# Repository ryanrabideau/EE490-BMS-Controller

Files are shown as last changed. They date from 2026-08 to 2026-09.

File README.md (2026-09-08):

# EE 490 - 24V Li-ion Battery Management System

This repository contains the hardware and firmware development for our EE 490 senior design project: a Battery Management System (BMS) for a custom **2P7S lithium-ion battery pack**.

The system uses an **STM32F411RE** microcontroller with an **ST L9963E** battery monitoring AFE and L9963T interface. The goal is to monitor individual cell voltages, pack current, temperature, and state of charge while providing fault detection, UART telemetry, and active cell balancing.

## System Overview

- **Battery configuration:** 2P7S
- **Cells:** Samsung INR18650-25R, 2.5 Ah per cell
- **Pack capacity:** 5.0 Ah
- **Nominal pack voltage:** 25.2 V
- **MCU:** STM32F411RE
- **Battery monitoring AFE:** ST L9963E
- **AFE interface:** ST L9963T
- **MCU/AFE communication:** SPI2
- **Telemetry:** USART2 UART
- **Firmware:** C using STM32 HAL
- **Balancing:** Chained switched-capacitor active balancing

## Firmware

The STM32 firmware is located in [`firmware/EE490BMS/`](firmware/EE490BMS/).

Communication with the L9963E is handled through the L9963T interface. The low-level driver handles register communication with the AFE, while the application layer processes the measurements and keeps track of the overall BMS state.

The firmware currently supports:

- L9963E initialization and addressing
- Register reads and writes
- Cell-voltage acquisition
- Pack-voltage calculation
- Minimum and maximum cell-voltage tracking
- Cell-to-cell voltage delta calculation
- Cell undervoltage and overvoltage detection
- Pack-current measurement using the L9963E current ADC
- Coulomb counting
- State-of-charge estimation
- Raw GPIO acquisition for the thermistors
- UART telemetry
- Communication and measurement timeouts
- Validity tracking for voltage, current, Coulomb-counting, and SoC data

The main application currently runs as a simple superloop with approximately one update per second. FreeRTOS files are still present in the generated STM32 project, but the BMS application itself does not currently use the RTOS scheduler.

## Current Progress

Communication between the STM32F411RE and L9963E is working, including device addressing and register reads/writes. Cell-voltage measurements have also been read successfully from the current four-cell bench setup.

The higher-level firmware for the final 7S system is now in place. This includes voltage processing, voltage fault detection, current sensing, Coulomb counting, SoC estimation, and UART telemetry. The current and Coulomb-counting code still needs to be validated on the complete hardware setup.

The final pack will use seven series cell groups, but the current bench configuration only enables **CELL1, CELL2, CELL13, and CELL14** on the L9963E. The final seven-cell channel mapping will be confirmed when the complete pack is connected.

Current sensing is implemented using the L9963E's 18-bit current ADC. The firmware currently contains a temporary **0.1 mΩ shunt value**, which will be replaced once the final shunt resistance is confirmed. Current polarity also needs to be verified on the physical hardware before the SoC calculation is considered final.

Temperature acquisition is partially implemented. The firmware can read the seven GPIO channels intended for the thermistors and convert the raw ADC values to voltages, but the final voltage-to-temperature conversion has not been added yet.

Active balancing is also still under development. The planned system uses a chained switched-capacitor topology, with the balancing hardware controlled by the STM32.

## UART Telemetry

The latest BMS measurements can be formatted and transmitted over USART2 for debugging and monitoring from a PC.

Example output:

```text
PACK: 25.184 V | CELLS: 3.598 3.602 3.596 3.600 3.595 3.601 3.592 V | CURRENT: -1.243 A | SOC: 81.7 % | VALID[V:1 I:1 SOC:1]
```

The validity flags make it possible to distinguish valid measurements from failed or incomplete AFE communication.

## Repository Structure

- [`firmware/`](firmware/) - STM32 firmware
  - [`EE490BMS/`](firmware/EE490BMS/) - Main STM32CubeIDE project
  - [`Core/Inc/`](firmware/EE490BMS/Core/Inc/) - Application and driver headers
  - [`Core/Src/`](firmware/EE490BMS/Core/Src/) - Application, driver, and STM32 source files
  - [`EE490BMS.ioc`](firmware/EE490BMS/EE490BMS.ioc) - STM32CubeMX configuration
- [`hardware/`](hardware/) - Battery pack, enclosure, and mechanical CAD
  - [`STL Exports/`](hardware/STL%20Exports/) - Exported 3D-printable parts
  - [`Vendor/`](hardware/Vendor/) - Vendor component models
- [`docs/`](docs/) - Project documentation
- [`pc_interface/`](pc_interface/) - PC-side interface development

## Main Firmware Files

[`bms_app.c`](firmware/EE490BMS/Core/Src/bms_app.c) and [`bms_app.h`](firmware/EE490BMS/Core/Inc/bms_app.h) contain the higher-level BMS logic, including voltage processing, current measurement, Coulomb counting, SoC estimation, fault detection, and telemetry.

[`L9963E_utils.c`](firmware/EE490BMS/Core/Src/L9963E_utils.c) and [`L9963E_utils.h`](firmware/EE490BMS/Core/Inc/L9963E_utils.h) provide the interface between the application layer and the L9963E driver.

[`L9963E.c`](firmware/EE490BMS/Core/Src/L9963E.c) and [`L9963E_drv.c`](firmware/EE490BMS/Core/Src/L9963E_drv.c) contain the lower-level L9963E functionality and communication.

[`stm32_if.c`](firmware/EE490BMS/Core/Src/stm32_if.c) provides the STM32 hardware interface used by the L9963E driver.

[`main.c`](firmware/EE490BMS/Core/Src/main.c) contains the STM32 initialization and main BMS superloop.

## Building the Firmware

The firmware is developed using **STM32CubeIDE** and **STM32CubeMX**.

The CubeIDE project is located in:

[`firmware/EE490BMS/`](firmware/EE490BMS/)

Import the project into STM32CubeIDE and build the Debug configuration. The current shared firmware builds with **0 errors and 0 warnings**.

## Remaining Work

The main remaining work is hardware integration and validation. This includes confirming the final seven-cell L9963E mapping, verifying the current shunt value and polarity, testing Coulomb-counting accuracy, validating SoC behavior during charge and discharge, completing the thermistor temperature conversion, and implementing the active-balancing control.

Mechanical work on the battery pack and control enclosure is also still in progress. Current SolidWorks assemblies and exported STL files can be found in the [`hardware/`](hardware/) directory.

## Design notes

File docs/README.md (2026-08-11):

System block diagrams, schematics, and register maps.

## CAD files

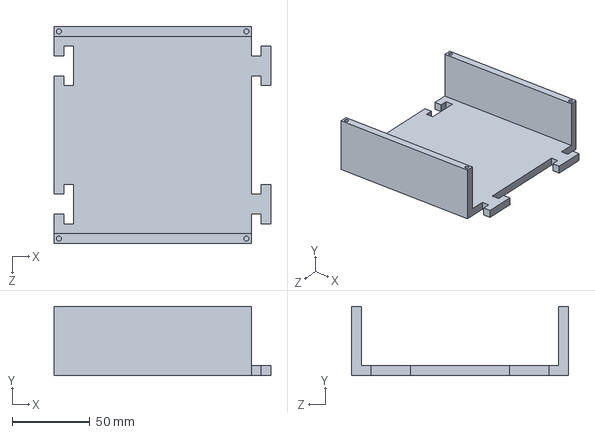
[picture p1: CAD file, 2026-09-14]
hardware/Battery Mount Middle.SLDPRT
139.7 x 44.5 x 139.7 mm

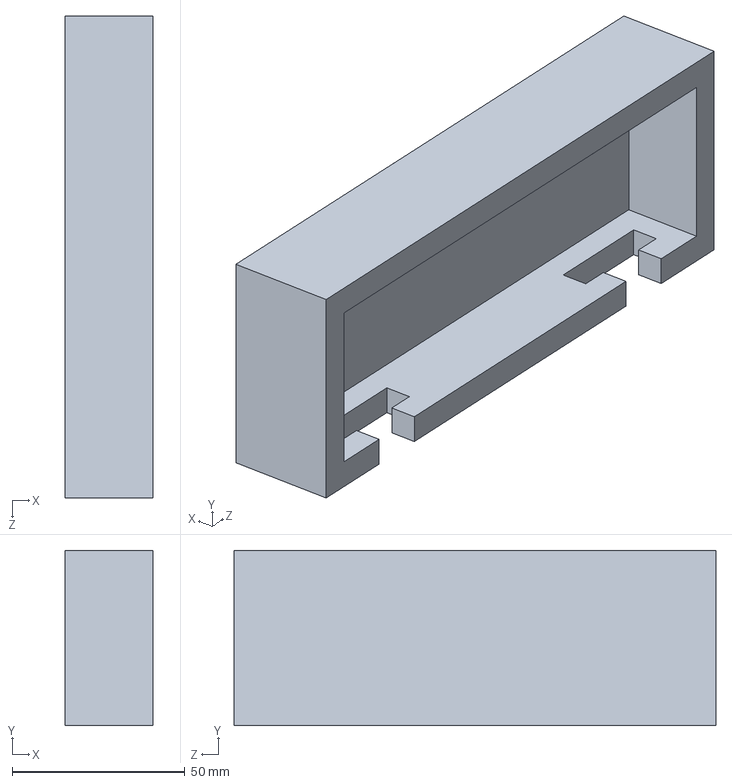
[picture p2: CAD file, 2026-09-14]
hardware/End Cap.SLDPRT
25.4 x 50.8 x 139.7 mm

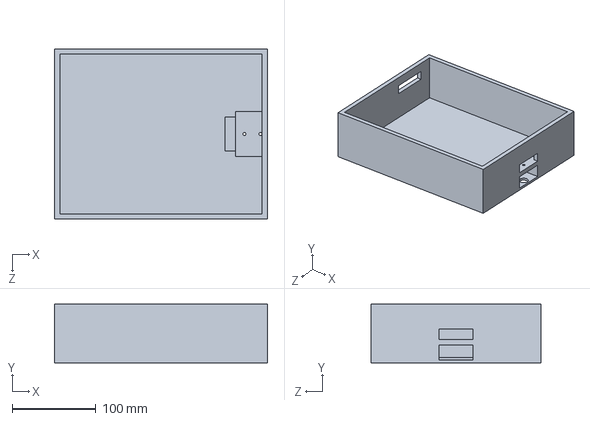
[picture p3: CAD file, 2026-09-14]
hardware/Control Enclosure.SLDPRT
254.0 x 69.8 x 203.2 mm

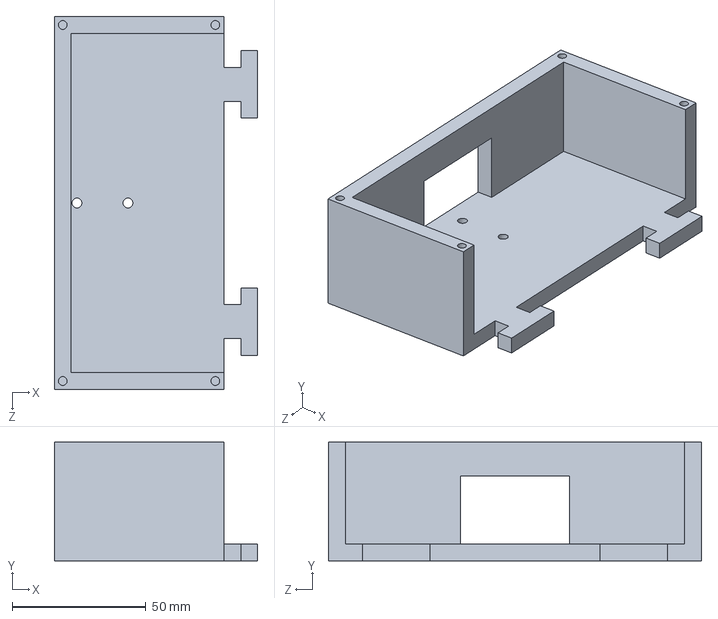
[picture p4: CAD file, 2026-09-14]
hardware/Battery Connector.SLDPRT
76.2 x 44.5 x 139.7 mm

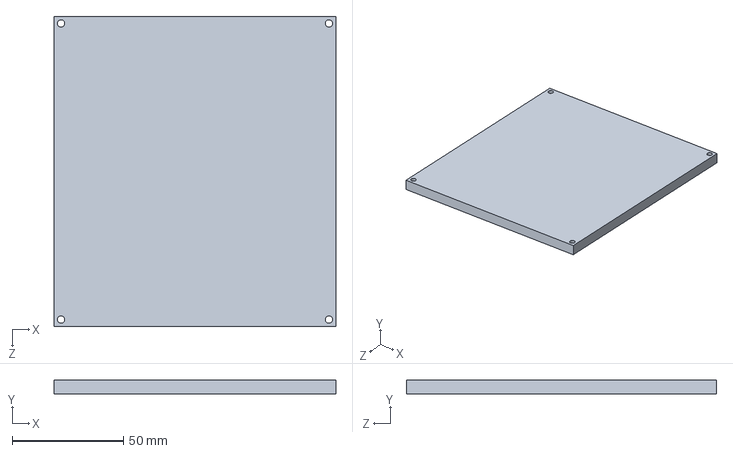
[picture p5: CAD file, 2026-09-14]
hardware/Battery Mount Middle Lid.SLDPRT
127.0 x 6.35 x 139.7 mm

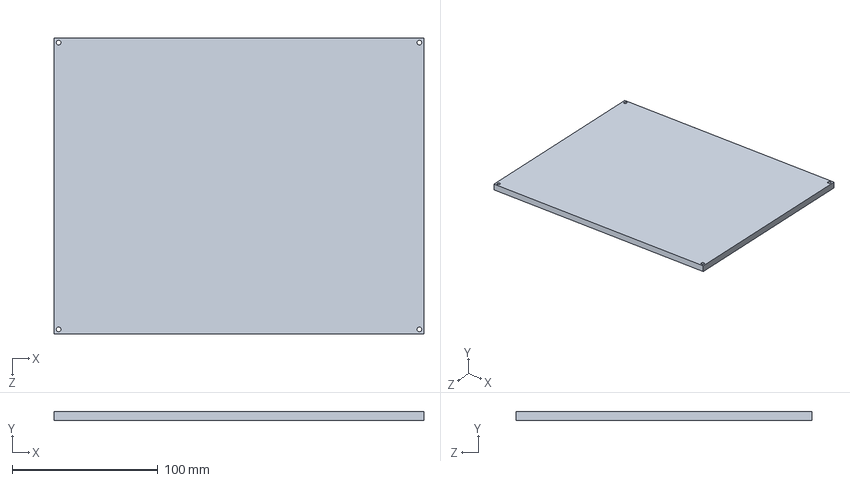
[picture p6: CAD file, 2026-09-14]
hardware/Control Enclosure Lid.SLDPRT
254.0 x 6.35 x 203.2 mm

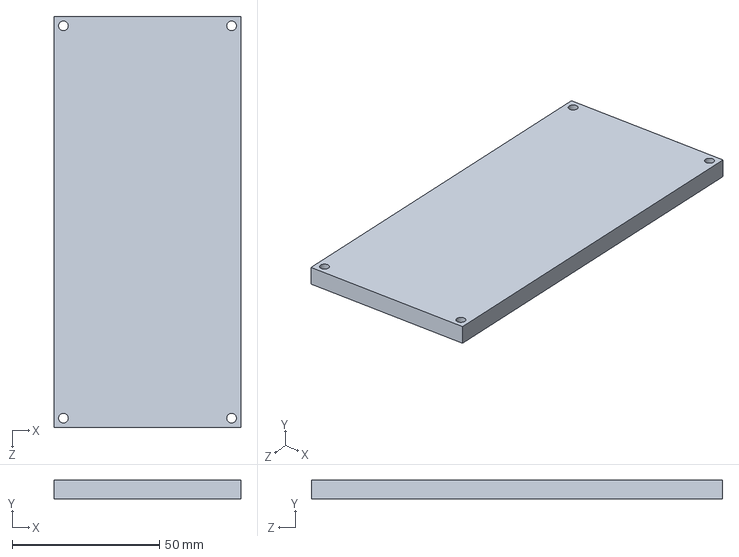
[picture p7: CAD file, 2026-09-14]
hardware/Battery Connector Lid.SLDPRT
63.5 x 6.35 x 139.7 mm

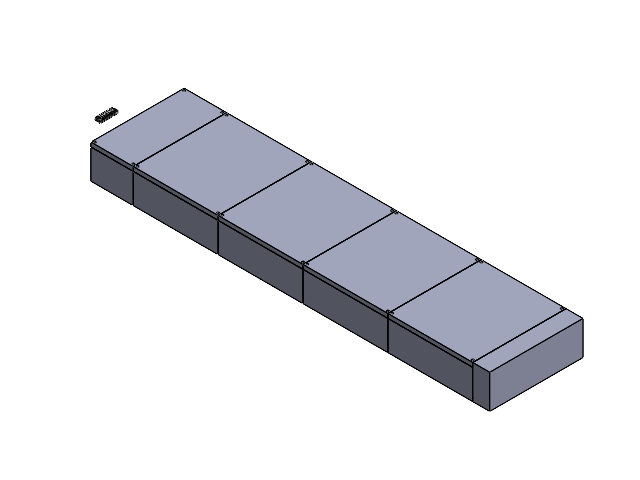
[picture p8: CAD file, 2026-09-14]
hardware/Battery Sub Component.SLDASM
BATTERY HOLDER x 8
Battery Mount Middle x 4
Battery Mount Middle Lid x 4
End Cap
Battery Connector
Anderson SB50
modele_pin.step x 10
Housing.step
Battery Connector Lid

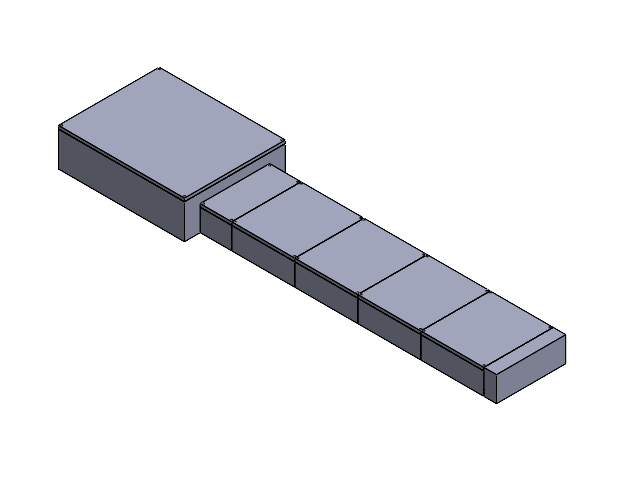
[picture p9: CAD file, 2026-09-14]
hardware/Layout.SLDASM
BATTERY HOLDER x 8
Battery Mount Middle x 4
Battery Mount Middle Lid x 4
End Cap
Battery Connector
Anderson SB50 x 2
modele_pin.step x 10
Housing.step
Battery Connector Lid
Control Enclosure
AEK-POW-BMSWTX Circuitboard
Pin.step x 10
Top_entry_base.step
MB1136 rev C.STEP
cn6.STEP
cn4.STEP
cn9.STEP
cn10.STEP
b1.STEP
b2.STEP
STM32lqfp64.STEP
cn8.STEP
cn7.STEP
jp1 kon.STEP x 2
cn1.STEP
X1_NUCLEO-F401RE.STEP
additional_NUCLEO-F401RE.STEP
jp1.STEP x 2
Jumper 1.STEP x 6
jp2_3 pin .STEP
jp2_2 pin.STEP x 2
T2.STEP
X2.STEP
L3.STEP
STM32F446RET6U.STEP
Breadboard
Control Enclosure Lid

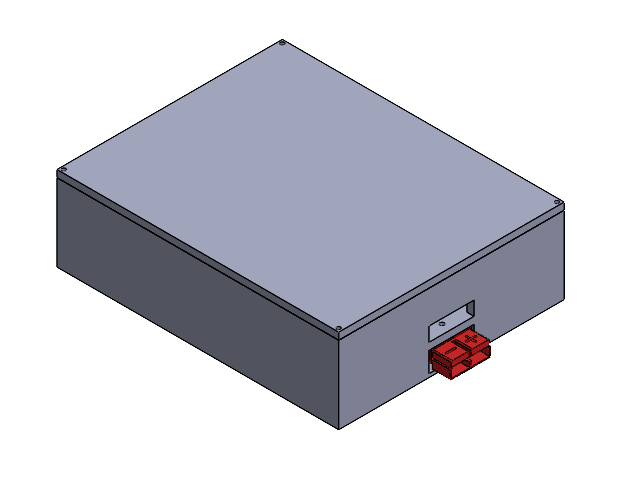
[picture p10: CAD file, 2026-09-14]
hardware/Control Assembly.SLDASM
Control Enclosure
AEK-POW-BMSWTX Circuitboard
Anderson SB50
Pin.step x 10
Top_entry_base.step
MB1136 rev C.STEP
cn6.STEP
cn4.STEP
cn9.STEP
cn10.STEP
b1.STEP
b2.STEP
STM32lqfp64.STEP
cn8.STEP
cn7.STEP
jp1 kon.STEP x 2
cn1.STEP
X1_NUCLEO-F401RE.STEP
additional_NUCLEO-F401RE.STEP
jp1.STEP x 2
Jumper 1.STEP x 6
jp2_3 pin .STEP
jp2_2 pin.STEP x 2
T2.STEP
X2.STEP
L3.STEP
STM32F446RET6U.STEP
Breadboard
Control Enclosure Lid

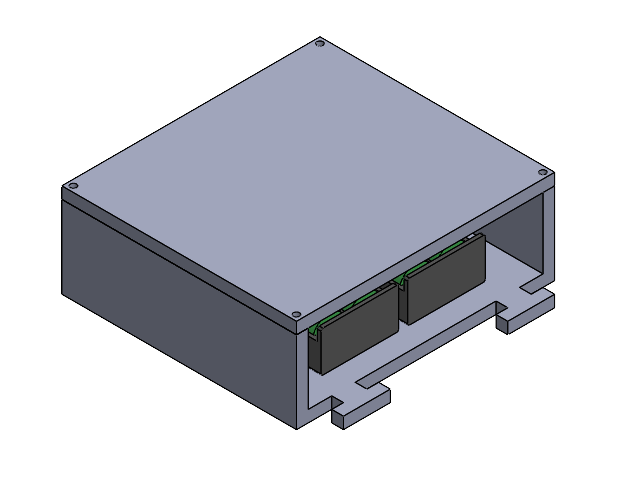
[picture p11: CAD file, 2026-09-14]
hardware/Middle Battery Setup.SLDASM
BATTERY HOLDER x 2
Battery Mount Middle
Battery Mount Middle Lid

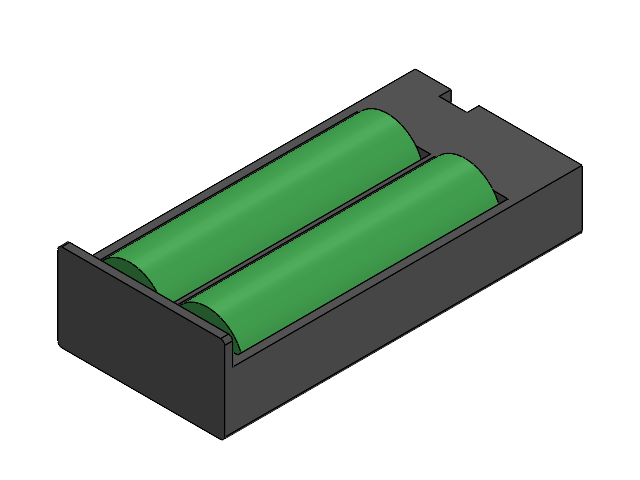
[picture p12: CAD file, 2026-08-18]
hardware/Filled Battery Holder.SLDASM
BATTERY HOLDER

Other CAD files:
hardware/STL Exports/Battery Connector Lid.STL
hardware/STL Exports/Battery Connector.STL
hardware/STL Exports/Battery Mount Middle Lid.STL
hardware/STL Exports/Battery Mount Middle.STL
hardware/STL Exports/Control Enclosure Lid.STL
hardware/STL Exports/Control Enclosure.STL
hardware/STL Exports/End Cap.STL

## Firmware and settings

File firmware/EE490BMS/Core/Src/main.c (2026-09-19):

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
/* Includes ------------------------------------------------------------------*/
#include "main.h"
#include "cmsis_os.h"

/* USER CODE BEGIN Includes */
#include "L9963E_utils.h"
#include "bms_app.h"
#include <stdint.h>
#include "THERMISTOR.h"
/* USER CODE END Includes */

ADC_HandleTypeDef hadc1;
DMA_HandleTypeDef hdma_adc1;

SPI_HandleTypeDef hspi2;

TIM_HandleTypeDef htim1;

UART_HandleTypeDef huart2;

/* Definitions for defaultTask */
osThreadId_t defaultTaskHandle;
const osThreadAttr_t defaultTask_attributes = {
  .name = "defaultTask",
  .stack_size = 128 * 4,
  .priority = (osPriority_t) osPriorityNormal,
};
void SystemClock_Config(void);
static void MX_GPIO_Init(void);
static void MX_DMA_Init(void);
static void MX_USART2_UART_Init(void);
static void MX_TIM1_Init(void);
static void MX_SPI2_Init(void);
static void MX_ADC1_Init(void);
void StartDefaultTask(void *argument);

/**
  * @brief  The application entry point.
  * @retval int
  */
int main(void)
{

  /* MCU Configuration--------------------------------------------------------*/

  /* Reset of all peripherals, Initializes the Flash interface and the Systick. */
  HAL_Init();

  /* Configure the system clock */
  SystemClock_Config();

  /* Initialize all configured peripherals */
  MX_GPIO_Init();
  MX_DMA_Init();
  MX_USART2_UART_Init();
  MX_TIM1_Init();
  MX_SPI2_Init();
  MX_ADC1_Init();
  /* USER CODE BEGIN 2 */

  char telemetryBuffer[256];
  int telemetryLength;
  uint32_t adcBuffer[4] = {0};	//0 is shunt current, 1-3 is temp
  float current = 0;
  float temp1 = 0;
  float temp2 = 0;
  float temp3 = 0;


  // Flash LED on board for reference and startup
  HAL_GPIO_WritePin(LD2_GPIO_Port, LD2_Pin, GPIO_PIN_SET);
  HAL_Delay(100);
  HAL_GPIO_WritePin(LD2_GPIO_Port,  LD2_Pin, GPIO_PIN_RESET);

  //Initialize global variable states
  BMS_App_Init();

  //Initialize and address the L9963E AFE.
  L9963E_utils_init();

  //Known SOC starting value
  BMS_App_SetSocReference(80.0f);

  HAL_GPIO_WritePin(SW_EVEN_GPIO_Port, SW_EVEN_Pin, GPIO_PIN_RESET);
  HAL_GPIO_WritePin(SW_ODD_GPIO_Port, SW_ODD_Pin, GPIO_PIN_RESET);


  //Used to test switching circuit

//  while (1) {
//	  HAL_GPIO_WritePin(SW_EVEN_GPIO_Port, SW_EVEN_Pin, GPIO_PIN_SET);
//	  HAL_Delay(10);
//	  HAL_GPIO_WritePin(SW_EVEN_GPIO_Port, SW_EVEN_Pin, GPIO_PIN_RESET);
//	  HAL_Delay(10);
//
//	  HAL_GPIO_WritePin(SW_ODD_GPIO_Port, SW_ODD_Pin, GPIO_PIN_SET);
//	  HAL_Delay(10);
//	  HAL_GPIO_WritePin(SW_ODD_GPIO_Port, SW_ODD_Pin, GPIO_PIN_RESET);
//	  HAL_Delay(10);
//  }

  HAL_NVIC_DisableIRQ(DMA2_Stream0_IRQn);
  HAL_ADC_Start_DMA(&hadc1, adcBuffer, 4);	//Start ADC with DMA of size 4

  // Super loop
  while (1)
  {
	  current = (adcBuffer[0]/(4096e0f))*6000;	// To mA
	  temp1 = Thermistor_ReadF(adcBuffer[1], 1);
	  temp2 = Thermistor_ReadF(adcBuffer[2], 0);
	  temp3 = Thermistor_ReadF(adcBuffer[3], 0);

	  BMS_App_SetExternalMeasurements(current, temp1, temp2, temp3);

	  BMS_App_UpdateAll();

	  const BMS_FaultData_t *faultData = BMS_App_GetFaultData();

	  if ((faultData != NULL) && !faultData->faultActive &&
			  temp1 < 85 && temp2 < 85 && temp3 < 85 && current < 2000)
	  {
	      HAL_GPIO_WritePin(MASTER_SWITCH_GPIO_Port, MASTER_SWITCH_Pin, GPIO_PIN_SET);
	  }
	  else
	  {
	      HAL_GPIO_WritePin(MASTER_SWITCH_GPIO_Port, MASTER_SWITCH_Pin, GPIO_PIN_RESET);
	  }

	  telemetryLength = BMS_App_FormatTelemetry(telemetryBuffer, sizeof(telemetryBuffer));

      if (telemetryLength > 0)
      {
          /*
           * snprintf() returns the number of characters
           * that would have been written.
           *
           * Limit transmission to the bytes actually
           * stored in telemetryBuffer.
           */
          uint16_t transmitLength = (telemetryLength < (int)sizeof(telemetryBuffer)) ?
              (uint16_t)telemetryLength :
              (uint16_t) (sizeof(telemetryBuffer) - 1U);

          HAL_UART_Transmit(&huart2, (uint8_t *)telemetryBuffer, transmitLength, HAL_MAX_DELAY);
      }

      //Keep Coulomb-counter servicing within the intended approximately one-second interval.
	  HAL_GPIO_WritePin(SW_EVEN_GPIO_Port, SW_EVEN_Pin, GPIO_PIN_SET);
	  HAL_Delay(10);
	  HAL_GPIO_WritePin(SW_EVEN_GPIO_Port, SW_EVEN_Pin, GPIO_PIN_RESET);
	  HAL_Delay(10);

	  HAL_GPIO_WritePin(SW_ODD_GPIO_Port, SW_ODD_Pin, GPIO_PIN_SET);
	  HAL_Delay(10);
	  HAL_GPIO_WritePin(SW_ODD_GPIO_Port, SW_ODD_Pin, GPIO_PIN_RESET);
	  HAL_Delay(10);
  }

  /* USER CODE END 2 */

  /* Init scheduler */
  osKernelInitialize();

  /* USER CODE BEGIN RTOS_MUTEX */
  /* add mutexes, ... */
  /* USER CODE END RTOS_MUTEX */

  /* USER CODE BEGIN RTOS_SEMAPHORES */
  /* add semaphores, ... */
  /* USER CODE END RTOS_SEMAPHORES */

  /* USER CODE BEGIN RTOS_TIMERS */
  /* start timers, add new ones, ... */
  /* USER CODE END RTOS_TIMERS */

  /* USER CODE BEGIN RTOS_QUEUES */
  /* add queues, ... */
  /* USER CODE END RTOS_QUEUES */

  /* Create the thread(s) */
  /* creation of defaultTask */
  defaultTaskHandle = osThreadNew(StartDefaultTask, NULL, &defaultTask_attributes);

  /* USER CODE BEGIN RTOS_THREADS */
  /* add threads, ... */
  /* USER CODE END RTOS_THREADS */

  /* USER CODE BEGIN RTOS_EVENTS */
  /* add events, ... */
  /* USER CODE END RTOS_EVENTS */

  /* Start scheduler */
  osKernelStart();

  /* We should never get here as control is now taken by the scheduler */

  /* Infinite loop */
  /* USER CODE BEGIN WHILE */
  while (1)
  {
    /* USER CODE END WHILE */

    /* USER CODE BEGIN 3 */
  }
  /* USER CODE END 3 */
}

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
/* USER CODE BEGIN Header_StartDefaultTask */
/**
  * @brief  Function implementing the defaultTask thread.
  * @param  argument: Not used
  * @retval None
  */
/* USER CODE END Header_StartDefaultTask */
void StartDefaultTask(void *argument)
{
  /* USER CODE BEGIN 5 */

  /* Infinite loop */
  for (;;)
  {
    osDelay(1);
  }

  /* USER CODE END 5 */
}

/**
  * @brief  Period elapsed callback in non blocking mode
  * @note   This function is called  when TIM5 interrupt took place, inside
  * HAL_TIM_IRQHandler(). It makes a direct call to HAL_IncTick() to increment
  * a global variable "uwTick" used as application time base.
  * @param  htim : TIM handle
  * @retval None
  */
void HAL_TIM_PeriodElapsedCallback(TIM_HandleTypeDef *htim)
{
  if (htim->Instance == TIM5)
  {
    HAL_IncTick();
  }
}

/**
  * @brief  This function is executed in case of error occurrence.
  * @retval None
  */
void Error_Handler(void)
{
  /* USER CODE BEGIN Error_Handler_Debug */

  /* User can add his own implementation to report the HAL error return state */

  __disable_irq();

  while (1)
  {
  }

  /* USER CODE END Error_Handler_Debug */
}
#ifdef USE_FULL_ASSERT
/**
  * @brief  Reports the name of the source file and the source line number
  *         where the assert_param error has occurred.
  * @param  file: pointer to the source file name
  * @param  line: assert_param error line source number
  * @retval None
  */
void assert_failed(uint8_t *file, uint32_t line)
{
  /* USER CODE BEGIN 6 */

  /* User can add his own implementation to report the file name and line number,
     ex: printf("Wrong parameters value: file %s on line %d\r\n", file, line) */

  /* USER CODE END 6 */
}
#endif /* USE_FULL_ASSERT */

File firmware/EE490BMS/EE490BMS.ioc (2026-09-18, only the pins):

Mcu.UserName=STM32F411RETx
PA0-WKUP.Signal=ADCx_IN0
PA13.GPIO_Label=TMS
PA13.Signal=SYS_JTMS-SWDIO
PA14.GPIO_Label=TCK
PA14.Signal=SYS_JTCK-SWCLK
PA2.GPIO_Label=USART_TX
PA2.Signal=USART2_TX
PA3.GPIO_Label=USART_RX
PA3.Signal=USART2_RX
PA4.Signal=ADCx_IN4
PA5.GPIO_Label=LD2 [Green Led]
PA5.Signal=GPIO_Output
PA6.Signal=ADCx_IN6
PA7.Signal=ADCx_IN7
PB0.GPIO_Label=L9963T_ISOFREQ_GPIO_OUT
PB0.Signal=GPIO_Output
PB1.GPIO_Label=L9963T_BNE_GPIO_IN
PB1.Signal=GPIO_Input
PB10.GPIO_Label=L9963T_SCK_SPI_SCK
PB10.Signal=SPI2_SCK
PB2.GPIO_Label=L9963T_TXEN_GPIO_OUT
PB2.Signal=GPIO_Output
PB3.GPIO_Label=SWO
PB3.Signal=SYS_JTDO-SWO
PB5.GPIO_Label=MASTER_SWITCH
PB5.Signal=GPIO_Output
PC0.GPIO_Label=SW_EVEN
PC0.Signal=GPIO_Output
PC1.GPIO_Label=SW_ODD
PC1.Signal=GPIO_Output
PC13-ANTI_TAMP.GPIO_Label=B1 [Blue PushButton]
PC13-ANTI_TAMP.Signal=GPXTI13
PC14-OSC32_IN.Signal=RCC_OSC32_IN
PC15-OSC32_OUT.Signal=RCC_OSC32_OUT
PC2.GPIO_Label=L9963T_SDO_SPI_MISO
PC2.Signal=SPI2_MISO
PC3.GPIO_Label=L9963T_SDI_SPI_MOSI
PC3.Signal=SPI2_MOSI
PC4.GPIO_Label=L9963T_NCS_GPIO_OUT
PC4.Signal=GPIO_Output
PC5.GPIO_Label=L9963T_DIS_GPIO_INOUT
PC5.Signal=GPIO_Output

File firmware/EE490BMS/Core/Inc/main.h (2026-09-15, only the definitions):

#define B1_Pin GPIO_PIN_13
#define B1_GPIO_Port GPIOC
#define SW_EVEN_Pin GPIO_PIN_0
#define SW_EVEN_GPIO_Port GPIOC
#define SW_ODD_Pin GPIO_PIN_1
#define SW_ODD_GPIO_Port GPIOC
#define L9963T_SDO_SPI_MISO_Pin GPIO_PIN_2
#define L9963T_SDO_SPI_MISO_GPIO_Port GPIOC
#define L9963T_SDI_SPI_MOSI_Pin GPIO_PIN_3
#define L9963T_SDI_SPI_MOSI_GPIO_Port GPIOC
#define USART_TX_Pin GPIO_PIN_2
#define USART_TX_GPIO_Port GPIOA
#define USART_RX_Pin GPIO_PIN_3
#define USART_RX_GPIO_Port GPIOA
#define LD2_Pin GPIO_PIN_5
#define LD2_GPIO_Port GPIOA
#define L9963T_NCS_GPIO_OUT_Pin GPIO_PIN_4
#define L9963T_NCS_GPIO_OUT_GPIO_Port GPIOC
#define L9963T_DIS_GPIO_INOUT_Pin GPIO_PIN_5
#define L9963T_DIS_GPIO_INOUT_GPIO_Port GPIOC
#define L9963T_ISOFREQ_GPIO_OUT_Pin GPIO_PIN_0
#define L9963T_ISOFREQ_GPIO_OUT_GPIO_Port GPIOB
#define L9963T_BNE_GPIO_IN_Pin GPIO_PIN_1
#define L9963T_BNE_GPIO_IN_GPIO_Port GPIOB
#define L9963T_TXEN_GPIO_OUT_Pin GPIO_PIN_2
#define L9963T_TXEN_GPIO_OUT_GPIO_Port GPIOB
#define L9963T_SCK_SPI_SCK_Pin GPIO_PIN_10
#define L9963T_SCK_SPI_SCK_GPIO_Port GPIOB
#define TMS_Pin GPIO_PIN_13
#define TMS_GPIO_Port GPIOA
#define TCK_Pin GPIO_PIN_14
#define TCK_GPIO_Port GPIOA
#define SWO_Pin GPIO_PIN_3
#define SWO_GPIO_Port GPIOB
#define MASTER_SWITCH_Pin GPIO_PIN_5
#define MASTER_SWITCH_GPIO_Port GPIOB

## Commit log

2026-08-11 Add README.md for EE 490 BMS Project
2026-08-11 Add README for STM32 C/C++ firmware project
2026-08-11 Add system block diagrams and schematics description
2026-08-11 battery holder part
2026-08-17 Working PWM Example
2026-08-18 Enclosure iteration
    [Battery Connector.SLDPRT, Battery Mount Middle.SLDPRT, Battery Sub Component.SLDASM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]
2026-08-24 -Defined SPI configuration in MX based on example project (Put L9963E communication on SPI2, but example project uses SPI1) -Added L9963E library source files -Modified library files so that project 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
2026-08-25 Add BMS cell voltage application logic
2026-08-25 Add BMS temperature input acquisition
2026-09-01 Larger space for perf board and cutout for serial and power input
    [Control Assembly.SLDASM, Control Enclosure.SLDPRT, Layout.SLDASM]
2026-09-05 Got voltage reading to work for 4 cells. Bottom cell is 1 V less than expected, though. Will have to look into that
2026-09-05 STLs (unfinished)
    [Battery Connector.STL, Battery Mount Middle.STL, Control Assembly.SLDASM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]
2026-09-06 Add BMS cell voltage fault detection
2026-09-07 Add L9963E current sensing support
2026-09-07 Add BMS coulomb counting support
2026-09-07 Add BMS state of charge estimation
2026-09-07 Add BMS UART telemetry formatting
2026-09-07 Add UART telemetry demo loop
2026-09-07 Harden L9963E acquisition and integrate BMS telemetry
2026-09-07 Fixed formatting of primary files
    [L9963E_utils.c, bms_app.c, main.c]
2026-09-08 Enhance README with project details and instructions
    Expanded the README to include detailed project information, system overview, firmware capabilities, current progress, UART telemetry, repository structure, main firmware files, building instructions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
2026-09-08 Working on current, but saving to fix sleep timeout
    [L9963E.c, L9963E_utils.c]
2026-09-09 Fixed commTimeOut issue and started to read current. Issue is that current does not change properly. Also started PC interface VI
    [L9963E_utils.c, bms_app.c]
2026-09-11 Design iteration
    [Battery Connector.SLDPRT, Battery Mount Middle.SLDPRT, Battery Sub Component.SLDASM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]
2026-09-12 Current and Voltage reading working on full pack
2026-09-14 Initial active balancing switching code
2026-09-15 Integrate voltage faults, UART telemetry, and master switch
2026-09-15 Adding Dillon Thermistor files
2026-09-15 Add temperature and current to UART telemetry
2026-09-15 STL Exports
    [Battery Connector Lid.STL, Battery Connector.STL, Battery Mount Middle Lid.STL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]
2026-09-16 Iniital ADC with shunt and temp pinouts
2026-09-16 Temp and current values found in main superloop
2026-09-16 #include "THERMISTOR.h"
2026-09-16 Route ADC current and temperatures to UART telemetry
2026-09-16 Added switching at bottom of main()
2026-09-18 Fixed ADC measurements, updated PC interface, and fixed relay logic. Everything "should work"
    [EE490BMS.ioc, bms_app.c, main.c]
2026-10-09 Update gitignore for STM32 build outputs
2026-10-09 Remove generated STM32 build files

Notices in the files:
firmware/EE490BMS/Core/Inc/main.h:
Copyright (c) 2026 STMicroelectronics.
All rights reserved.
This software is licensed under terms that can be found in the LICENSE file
